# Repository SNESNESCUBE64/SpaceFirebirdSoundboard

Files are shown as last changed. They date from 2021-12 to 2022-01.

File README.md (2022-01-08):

# Space Firebird Soundboard Reproduction
This was my attempt at making a reproduction sound board for Space Firebird. It is a pretty fun game but I was having problems finding the sound boards. This reproduction board is not a 1:1 recreation, that would be silly. But it should fit in an original cocktail table or upright but that is not confirmed. I have a couple quality of life improvements, like for example all axial capacitors have been replaced with radials. I also used copper pours for the grounding in this. It does roughly follow the original layout however. These are not going to be really for sale by myself, which is why I am uploading the files so you can make your own!

**Status**: Prototype PCBs were assembled and tested as functional.

## Schematic Notes
Believe it or not, there were actually a couple of mistakes in the original schematics. The first one is IC12 pin 13. In the original schematics, it connects to pin 6 of IC9, this is incorrect, it should be connected to pin 4. Another thing I corrected is in later revisions of the sound board, they added two capacitors to the clear lines on the 74ls164s. Some older revisions have these capacitors hacked on, I went ahead and added them so hacks aren't necessary. One final thing I changed is if I read the schematics right, it was originally strapped for 2708 eproms, I changed the default to 2716 as those are much easier to program for.

## Images
**Front Render**   
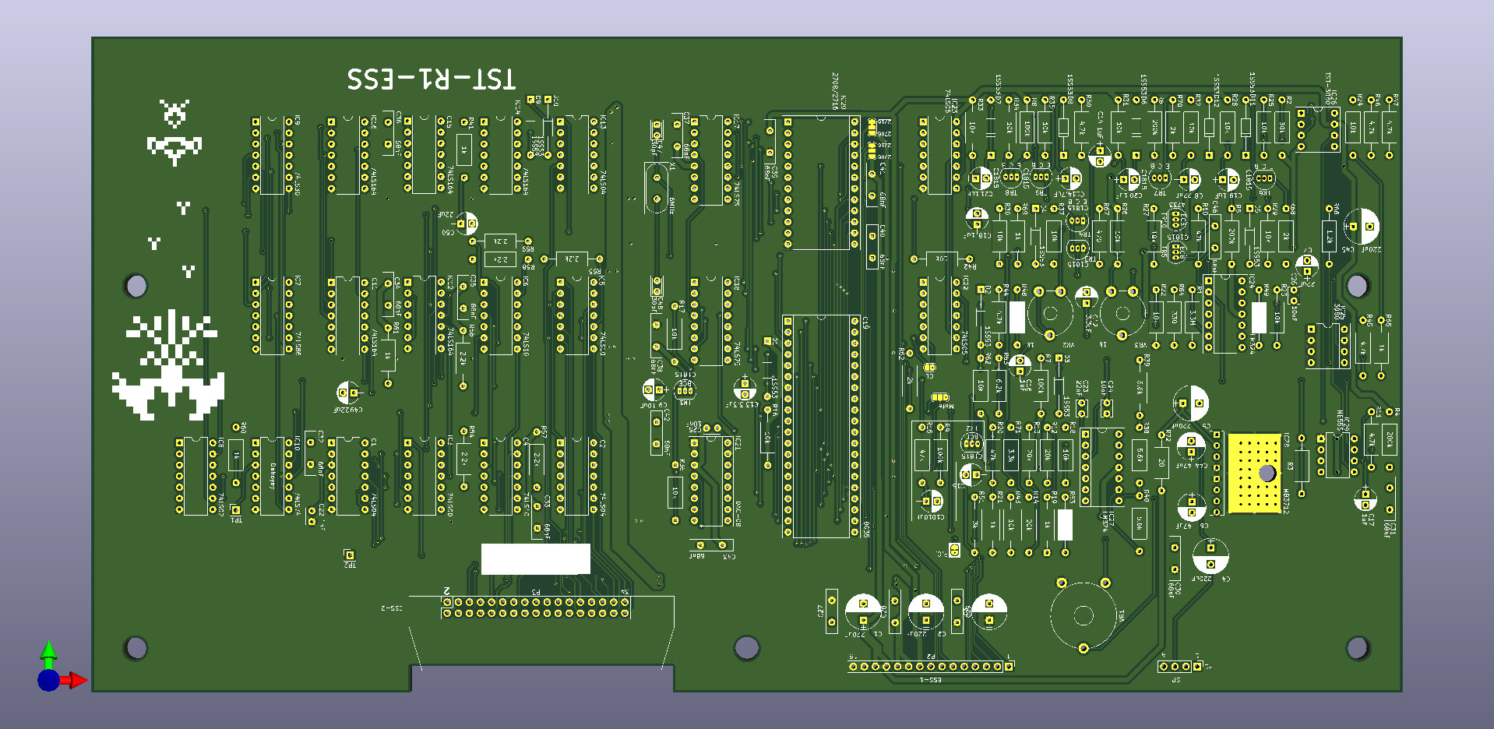
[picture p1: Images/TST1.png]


**Back Render**  
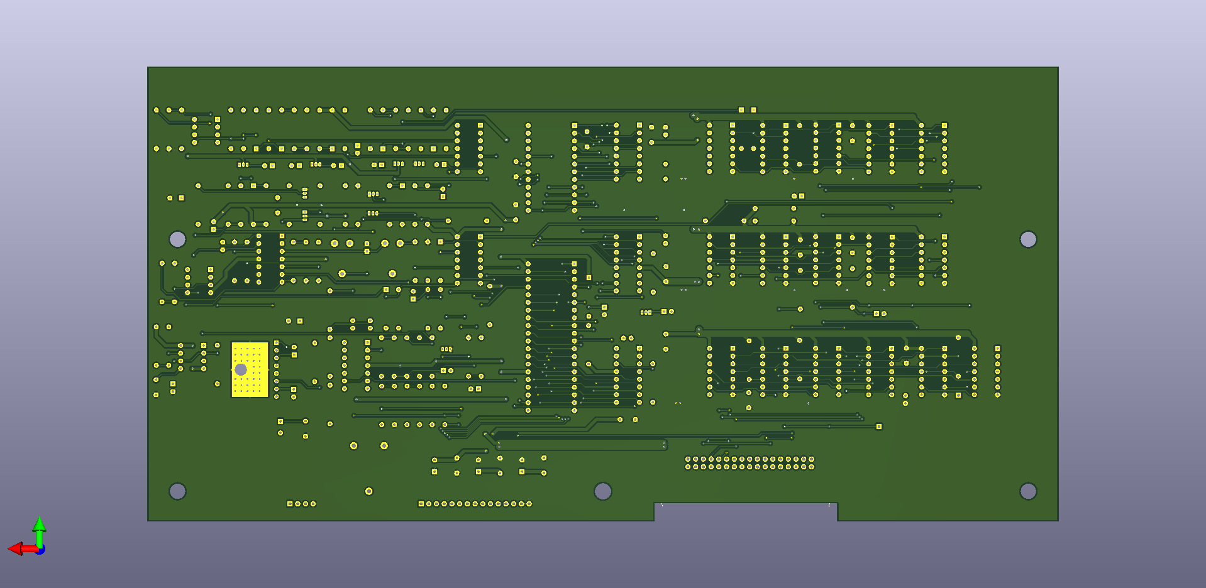
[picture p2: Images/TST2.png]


**Prototype PCB Front**  
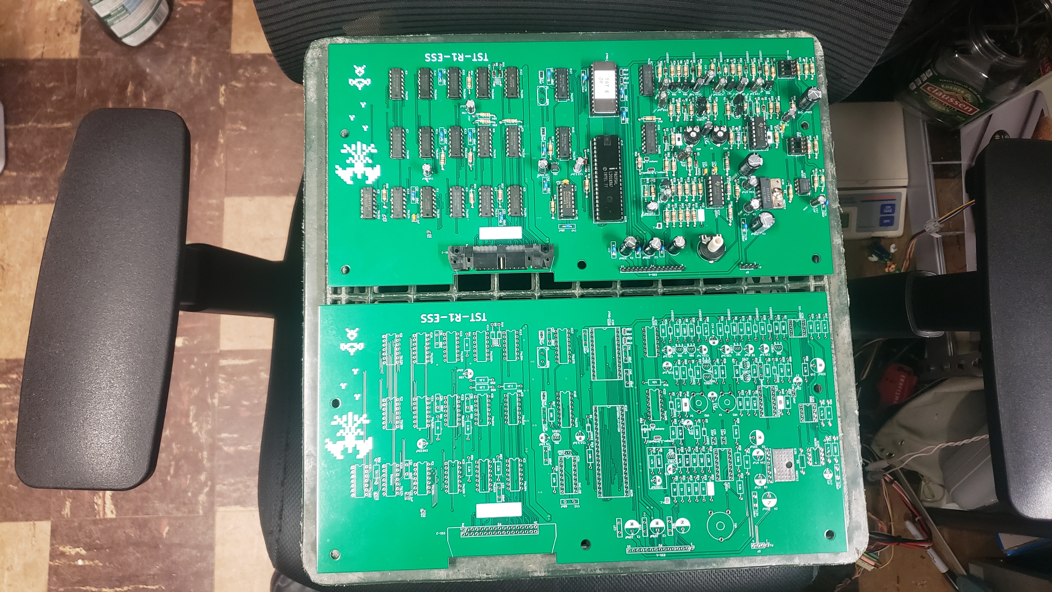
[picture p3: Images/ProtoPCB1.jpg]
Prototype Front


**Prototype PCB Back**  
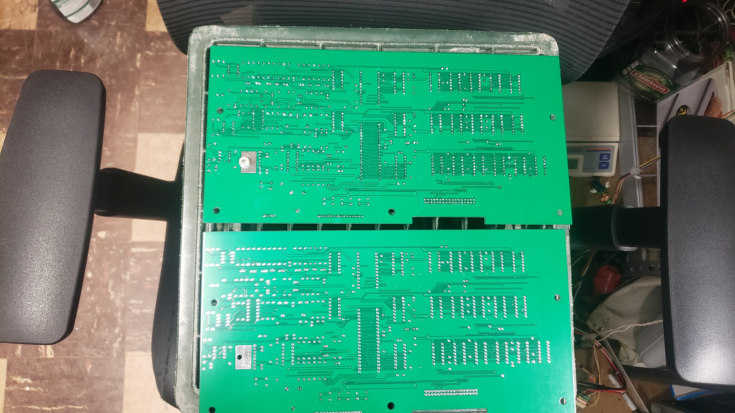
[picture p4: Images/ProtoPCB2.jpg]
Prototype Back


## Part Substitutions
- DAC-08
  - DAC0808LCN
- MB3712
  - ECG1423
  - NTE1423
- CA3080E (DIP Package Only)
  - LM3080N
  - ECG996
  - NTE996

## Bill of Materials
Most parts that are used on this sound board are off the shelf componts that are still made today. The only ones you might have a problem with are the eprom (strapped for 2716 by default), the 8035 CPU, CA3080E, and MB3712. Some components are not populated. X1, C47, C48, R48, R49, and R53 are not supposed to be populated. Some components are being substituted, for example: 1ss53 diodes are being substituted for 1N4148. 

|Item |Qty  |Reference(s) |Value |LibPart |Footprint |
|-----|---|---|---|---|---|
|1 |5 |C1, C2, C3, C4, C45 |220uF |Device:CP |Capacitors_THT:CP_Radial_D8.0mm_P3.80mm |
|2 |1 |C5 |220uf |Device:CP |Capacitors_THT:CP_Radial_D8.0mm_P3.80mm |
|3 |2 |C6, C44 |47uF |Device:CP |Capacitors_THT:CP_Radial_D6.3mm_P2.50mm |
|4 |4 |C7, C8, C49, C50 |22uF |Device:CP |Capacitors_THT:CP_Radial_D5.0mm_P2.50mm |
|5 |2 |C9, C10 |10uF |Device:CP |Capacitors_THT:CP_Radial_D5.0mm_P2.50mm |
|6 |1 |C11 |4.7uF |Device:CP |Capacitors_THT:CP_Radial_D5.0mm_P2.50mm |
|7 |2 |C12, C13 |3.3uF |Device:CP |Capacitors_THT:CP_Radial_D5.0mm_P2.50mm |
|8 |8 |C14, C15, C16, C17, C18, C19, C20, C21 |1uF |Device:CP |Capacitors_THT:CP_Radial_D5.0mm_P2.50mm |
|9 |1 |C22 |1nF |Device:C |Capacitors_THT:C_Disc_D3.8mm_W2.6mm_P2.50mm |
|10 |1 |C23 |22nF |Device:C |Capacitors_THT:C_Disc_D3.8mm_W2.6mm_P2.50mm |
|11 |3 |C24, C25, C26 |10nF |Device:C |Capacitors_THT:C_Disc_D3.8mm_W2.6mm_P2.50mm |
|12 |18 |C27, C28, C29, C30, C31, C32, C33, C34, C35, C36, C37, C38, C39, C40, C41, C42, C43, C46 |68nF |Device:C |Capacitors_THT:C_Disc_D10.0mm_W2.5mm_P5.00mm |
|13 |2 |C47, C48 |30pF |Device:C |Capacitors_THT:C_Disc_D3.4mm_W2.1mm_P2.50mm |
|14 |12 |D1, D2, D3, D4, D5, D6, D7, D8, D9, D10, D11, D12 |1SS53 (1N4148) |Device:D |Diodes_THT:D_DO-35_SOD27_P12.70mm_Horizontal |
|15 |3 |IC1, IC2, IC13 |74LS04 |74xx:74LS04 |Housings_DIP:DIP-14_W7.62mm |
|16 |1 |IC3 |74LS00 |74xx:74LS00 |Housings_DIP:DIP-14_W7.62mm |
|17 |3 |IC4, IC5, IC6 |74LS10 |74xx:74LS10 |Housings_DIP:DIP-14_W7.62mm |
|18 |1 |IC7 |74LS86 |74xx:74LS86 |Housings_DIP:DIP-14_W7.62mm |
|19 |1 |IC8 |74LS02 |74xx:74LS02 |Housings_DIP:DIP-14_W7.62mm |
|20 |1 |IC9 |74LS30 |74xx:74LS30 |Housings_DIP:DIP-14_W7.62mm |
|21 |1 |IC10 |74LS74 |74xx:74LS74 |Housings_DIP:DIP-14_W7.62mm |
|22 |5 |IC11, IC12, IC14, IC15, IC16 |74LS164 |Custom_Symbols:74LS164 |Housings_DIP:DIP-14_W7.62mm |
|23 |2 |IC17, IC18 |74LS75 |74xx:74LS75 |Housings_DIP:DIP-16_W7.62mm |
|24 |1 |IC19 |TST-8035 |Custom_Symbols:TST-8035 |Housings_DIP:DIP-40_W15.24mm_Socket |
|25 |1 |IC20 |TST-2708 |Custom_Symbols:TST-2716 |Housings_DIP:DIP-24_W15.24mm_Socket |
|26 |1 |IC21 |TST-DAC08 |Custom_Symbols:TST-DAC08 |Housings_DIP:DIP-16_W7.62mm_Socket |
|27 |2 |IC22, IC23 |74LS05 |74xx:74LS05 |Housings_DIP:DIP-14_W7.62mm |
|28 |2 |IC24, IC27 |LM324A |Amplifier_Operational:LM324A |Housings_DIP:DIP-14_W7.62mm_Socket |
|29 |2 |IC25, IC26 |TST-3080 |Custom_Symbols:TST-3080 |Housings_DIP:DIP-8_W7.62mm_Socket |
|30 |1 |IC28 |TST-MB3712 |Custom_Symbols:TST-MB3712 |Custom Footprints:MB3712 |
|31 |1 |IC29 |TST-NE555 |Custom_Symbols:TST-NE555 |Housings_DIP:DIP-8_W7.62mm |
|32 |3 |JP1, JP2, JP3 |Jumper_3_Bridged12 |Jumper:Jumper_3_Bridged12 |Jumpers:SolderJumper-3_P1.3mm_Bridged12_RoundedPad1.0x1.5mm_NumberLabels |
|33 |4 |JP4, JP5, JP6, JP7 |Jumper_2_Bridged |Jumper:Jumper_2_Bridged |Jumpers:SolderJumper-2_P1.3mm_Bridged_RoundedPad1.0x1.5mm |
|34 |1 |P1 |Conn_01x04 |Connector_Generic:Conn_01x04 |Pin_Headers:Pin_Header_Straight_1x04_Pitch2.54mm |
|35 |1 |P2 |Conn_01x15 |Connector_Generic:Conn_01x15 |Pin_Headers:Pin_Header_Straight_1x15_Pitch2.54mm |
|36 |1 |P3 |Conn_02x17_Odd_Even|Connector_Generic:Conn_02x17_Odd_Even|Custom Footprints:34_right_angle_ribbon |
|37 |1 |R1 |3.3M |Device:R |Custom Footprints:R_Axial_DIN0309_L7.0mm_D3.2mm_P12.70mm_Horizontal |
|38 |1 |R2 |30k |Device:R |Custom Footprints:R_Axial_DIN0309_L7.0mm_D3.2mm_P12.70mm_Horizontal |
|39 |1 |R3 |470k |Device:R |Custom Footprints:R_Axial_DIN0309_L7.0mm_D3.2mm_P12.70mm_Horizontal |
|40 |3 |R4, R5, R6 |200k |Device:R |Custom Footprints:R_Axial_DIN0309_L7.0mm_D3.2mm_P12.70mm_Horizontal |
|41 |3 |R7, R8, R9 |100k |Device:R |Custom Footprints:R_Axial_DIN0309_L7.0mm_D3.2mm_P12.70mm_Horizontal |
|42 |3 |R10, R15, R20 |47k |Device:R |Custom Footprints:R_Axial_DIN0309_L7.0mm_D3.2mm_P12.70mm_Horizontal |
|43 |6 |R11, R44, R45, R46, R47, R50 |4.7k |Device:R |Custom Footprints:R_Axial_DIN0309_L7.0mm_D3.2mm_P12.70mm_Horizontal |
|44 |3 |R12, R13, R14 |20k |Device:R |Custom Footprints:R_Axial_DIN0309_L7.0mm_D3.2mm_P12.70mm_Horizontal |
|45 |22 |R16, R17, R18, R22, R23, R24, R25, R26, R27, R28, R29, R30, R31, R32, R33, R34, R35, R36, R37, R42, R43, R62|10k |Device:R |Custom Footprints:R_Axial_DIN0309_L7.0mm_D3.2mm_P12.70mm_Horizontal |
|46 |7 |R19, R21, R41, R60, R61, R65, R69 |1k |Device:R |Custom Footprints:R_Axial_DIN0309_L7.0mm_D3.2mm_P12.70mm_Horizontal |
|47 |3 |R38, R39, R40 |5.6k |Device:R |Custom Footprints:R_Axial_DIN0309_L7.0mm_D3.2mm_P12.70mm_Horizontal |
|48 |2 |R48, R49 |1 |Device:R |Custom Footprints:R_Axial_DIN0309_L7.0mm_D3.2mm_P12.70mm_Horizontal |
|49 |1 |R51 |3k |Device:R |Custom Footprints:R_Axial_DIN0309_L7.0mm_D3.2mm_P12.70mm_Horizontal |
|50 |3 |R52, R68, R70 |2k |Device:R |Custom Footprints:R_Axial_DIN0309_L7.0mm_D3.2mm_P12.70mm_Horizontal |
|51 |1 |R53 |0 |Device:R |Custom Footprints:R_Axial_DIN0309_L7.0mm_D3.2mm_P12.70mm_Horizontal |
|52 |6 |R54, R55, R56, R57, R58, R59 |2.2k |Device:R |Custom Footprints:R_Axial_DIN0309_L7.0mm_D3.2mm_P12.70mm_Horizontal |
|53 |1 |R63 |6.2k |Device:R |Custom Footprints:R_Axial_DIN0309_L7.0mm_D3.2mm_P12.70mm_Horizontal |
|54 |1 |R64 |330 |Device:R |Custom Footprints:R_Axial_DIN0309_L7.0mm_D3.2mm_P12.70mm_Horizontal |
|55 |1 |R66 |1.2k |Device:R |Custom Footprints:R_Axial_DIN0309_L7.0mm_D3.2mm_P12.70mm_Horizontal |
|56 |1 |R67 |470 |Device:R |Custom Footprints:R_Axial_DIN0309_L7.0mm_D3.2mm_P12.70mm_Horizontal |
|57 |1 |R71 |3.3k |Device:R |Custom Footprints:R_Axial_DIN0309_L7.0mm_D3.2mm_P12.70mm_Horizontal |
|58 |1 |R72 |20 |Device:R |Custom Footprints:R_Axial_DIN0309_L7.0mm_D3.2mm_P12.70mm_Horizontal |
|59 |9 |TR1, TR2, TR3, TR4, TR5, TR6, TR7, TR8, TR9 |2SC1815 |Transistor_BJT:2SC1815 |TO_SOT_Packages_THT:TO-92_Inline_Narrow_Oval |
|60 |1 |TR10 |2SA733 |Device:Q_PNP_ECB |TO_SOT_Packages_THT:TO-92_Inline_Narrow_Oval |
|61 |1 |VR1 |10k |Device:R_POT |Potentiometers:Potentiometer_Trimmer_Piher_PT-15v15_Horizontal_Px15.0mm_Py10.0mm|
|62 |2 |VR2, VR3 |1k |Device:R_POT |Potentiometers:Potentiometer_Trimmer_Piher_PT-10v10_Horizontal_Px10.0mm_Py5.0mm |
|63 |1 |X1 |6MHz |Device:Crystal |Crystals:Crystal_HC18-U_Vertical |

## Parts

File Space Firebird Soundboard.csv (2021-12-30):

Source: | Space Firebird Soundboard.sch
Date: | 12/28/2021 20:36
Tool: | Eeschema (5.1.4)-1
Generator: | C:\Program Files\KiCad\bin\scripting\plugins/bom_csv_grouped_by_value.py
Component Count: | 187
Individual Components:
Item | Qty | Reference(s) | Value | LibPart | Footprint | Datasheet
 |  | C1 | 220uF | Device:CP | Capacitors_THT:CP_Radial_D8.0mm_P3.80mm | ~
 |  | C2 | 220uF | Device:CP | Capacitors_THT:CP_Radial_D8.0mm_P3.80mm | ~
 |  | C3 | 220uF | Device:CP | Capacitors_THT:CP_Radial_D8.0mm_P3.80mm | ~
 |  | C4 | 220uF | Device:CP | Capacitors_THT:CP_Radial_D8.0mm_P3.80mm | ~
 |  | C5 | 220uf | Device:CP | Capacitors_THT:CP_Radial_D8.0mm_P3.80mm | ~
 |  | C6 | 47uF | Device:CP | Capacitors_THT:CP_Radial_D6.3mm_P2.50mm | ~
 |  | C7 | 22uF | Device:CP | Capacitors_THT:CP_Radial_D5.0mm_P2.50mm | ~
 |  | C8 | 22uF | Device:CP | Capacitors_THT:CP_Radial_D5.0mm_P2.50mm | ~
 |  | C9 | 10uF | Device:CP | Capacitors_THT:CP_Radial_D5.0mm_P2.50mm | ~
 |  | C10 | 10uF | Device:CP | Capacitors_THT:CP_Radial_D5.0mm_P2.50mm | ~
 |  | C11 | 4.7uF | Device:CP | Capacitors_THT:CP_Radial_D5.0mm_P2.50mm | ~
 |  | C12 | 3.3uF | Device:CP | Capacitors_THT:CP_Radial_D5.0mm_P2.50mm | ~
 |  | C13 | 3.3uF | Device:CP | Capacitors_THT:CP_Radial_D5.0mm_P2.50mm | ~
 |  | C14 | 1uF | Device:CP | Capacitors_THT:CP_Radial_D5.0mm_P2.50mm | ~
 |  | C15 | 1uF | Device:CP | Capacitors_THT:CP_Radial_D5.0mm_P2.50mm | ~
 |  | C16 | 1uF | Device:CP | Capacitors_THT:CP_Radial_D5.0mm_P2.50mm | ~
 |  | C17 | 1uF | Device:CP | Capacitors_THT:CP_Radial_D5.0mm_P2.50mm | ~
 |  | C18 | 1uF | Device:CP | Capacitors_THT:CP_Radial_D5.0mm_P2.50mm | ~
 |  | C19 | 1uF | Device:CP | Capacitors_THT:CP_Radial_D5.0mm_P2.50mm | ~
 |  | C20 | 1uF | Device:CP | Capacitors_THT:CP_Radial_D5.0mm_P2.50mm | ~
 |  | C21 | 1uF | Device:CP | Capacitors_THT:CP_Radial_D5.0mm_P2.50mm | ~
 |  | C22 | 1nF | Device:C | Capacitors_THT:C_Disc_D3.8mm_W2.6mm_P2.50mm | ~
 |  | C23 | 22nF | Device:C | Capacitors_THT:C_Disc_D3.8mm_W2.6mm_P2.50mm | ~
 |  | C24 | 10nF | Device:C | Capacitors_THT:C_Disc_D3.8mm_W2.6mm_P2.50mm | ~
 |  | C25 | 10nF | Device:C | Capacitors_THT:C_Disc_D3.8mm_W2.6mm_P2.50mm | ~
 |  | C26 | 10nF | Device:C | Capacitors_THT:C_Disc_D3.8mm_W2.6mm_P2.50mm | ~
 |  | C27 | 68nF | Device:C | Capacitors_THT:C_Disc_D10.0mm_W2.5mm_P5.00mm | ~
 |  | C28 | 68nF | Device:C | Capacitors_THT:C_Disc_D10.0mm_W2.5mm_P5.00mm | ~
 |  | C29 | 68nF | Device:C | Capacitors_THT:C_Disc_D10.0mm_W2.5mm_P5.00mm | ~
 |  | C30 | 68nF | Device:C | Capacitors_THT:C_Disc_D10.0mm_W2.5mm_P5.00mm | ~
 |  | C31 | 68nF | Device:C | Capacitors_THT:C_Disc_D10.0mm_W2.5mm_P5.00mm | ~
 |  | C32 | 68nF | Device:C | Capacitors_THT:C_Disc_D10.0mm_W2.5mm_P5.00mm | ~
 |  | C33 | 68nF | Device:C | Capacitors_THT:C_Disc_D10.0mm_W2.5mm_P5.00mm | ~
 |  | C34 | 68nF | Device:C | Capacitors_THT:C_Disc_D10.0mm_W2.5mm_P5.00mm | ~
 |  | C35 | 68nF | Device:C | Capacitors_THT:C_Disc_D10.0mm_W2.5mm_P5.00mm | ~
 |  | C36 | 68nF | Device:C | Capacitors_THT:C_Disc_D10.0mm_W2.5mm_P5.00mm | ~
 |  | C37 | 68nF | Device:C | Capacitors_THT:C_Disc_D10.0mm_W2.5mm_P5.00mm | ~
 |  | C38 | 68nF | Device:C | Capacitors_THT:C_Disc_D10.0mm_W2.5mm_P5.00mm | ~
 |  | C39 | 68nF | Device:C | Capacitors_THT:C_Disc_D10.0mm_W2.5mm_P5.00mm | ~
 |  | C40 | 68nF | Device:C | Capacitors_THT:C_Disc_D10.0mm_W2.5mm_P5.00mm | ~
 |  | C41 | 68nF | Device:C | Capacitors_THT:C_Disc_D10.0mm_W2.5mm_P5.00mm | ~
 |  | C42 | 68nF | Device:C | Capacitors_THT:C_Disc_D10.0mm_W2.5mm_P5.00mm | ~
 |  | C43 | 68nF | Device:C | Capacitors_THT:C_Disc_D10.0mm_W2.5mm_P5.00mm | ~
 |  | C44 | 47uF | Device:CP | Capacitors_THT:CP_Radial_D6.3mm_P2.50mm | ~
 |  | C45 | 220uF | Device:CP | Capacitors_THT:CP_Radial_D8.0mm_P3.80mm | ~
 |  | C46 | 68nF | Device:C | Capacitors_THT:C_Disc_D10.0mm_W2.5mm_P5.00mm | ~
 |  | C47 | 30pF | Device:C | Capacitors_THT:C_Disc_D3.4mm_W2.1mm_P2.50mm | ~
 |  | C48 | 30pF | Device:C | Capacitors_THT:C_Disc_D3.4mm_W2.1mm_P2.50mm | ~
 |  | C49 | 22uF | Device:CP | Capacitors_THT:CP_Radial_D5.0mm_P2.50mm | ~
 |  | C50 | 22uF | Device:CP | Capacitors_THT:CP_Radial_D5.0mm_P2.50mm | ~
 |  | D1 | 1SS53 (1N4148) | Device:D | Diodes_THT:D_DO-35_SOD27_P12.70mm_Horizontal | ~
 |  | D2 | 1SS53 (1N4148) | Device:D | Diodes_THT:D_DO-35_SOD27_P12.70mm_Horizontal | ~
 |  | D3 | 1SS53 (1N4148) | Device:D | Diodes_THT:D_DO-35_SOD27_P12.70mm_Horizontal | ~
 |  | D4 | 1SS53 (1N4148) | Device:D | Diodes_THT:D_DO-35_SOD27_P12.70mm_Horizontal | ~
 |  | D5 | 1SS53 (1N4148) | Device:D | Diodes_THT:D_DO-35_SOD27_P12.70mm_Horizontal | ~
 |  | D6 | 1SS53 (1N4148) | Device:D | Diodes_THT:D_DO-35_SOD27_P12.70mm_Horizontal | ~
 |  | D7 | 1SS53 (1N4148) | Device:D | Diodes_THT:D_DO-35_SOD27_P12.70mm_Horizontal | ~
 |  | D8 | 1SS53 (1N4148) | Device:D | Diodes_THT:D_DO-35_SOD27_P12.70mm_Horizontal | ~
 |  | D9 | 1SS53 (1N4148) | Device:D | Diodes_THT:D_DO-35_SOD27_P12.70mm_Horizontal | ~
 |  | D10 | 1SS53 (1N4148) | Device:D | Diodes_THT:D_DO-35_SOD27_P12.70mm_Horizontal | ~
 |  | D11 | 1SS53 (1N4148) | Device:D | Diodes_THT:D_DO-35_SOD27_P12.70mm_Horizontal | ~
 |  | D12 | 1SS53 (1N4148) | Device:D | Diodes_THT:D_DO-35_SOD27_P12.70mm_Horizontal | ~
 |  | IC1 | 74LS04 | 74xx:74LS04 | Housings_DIP:DIP-14_W7.62mm | http://www.ti.com/lit/gpn/sn74LS04
 |  | IC2 | 74LS04 | 74xx:74LS04 | Housings_DIP:DIP-14_W7.62mm | http://www.ti.com/lit/gpn/sn74LS04
 |  | IC3 | 74LS00 | 74xx:74LS00 | Housings_DIP:DIP-14_W7.62mm | http://www.ti.com/lit/gpn/sn74ls00
 |  | IC4 | 74LS10 | 74xx:74LS10 | Housings_DIP:DIP-14_W7.62mm | http://www.ti.com/lit/gpn/sn74LS10
 |  | IC5 | 74LS10 | 74xx:74LS10 | Housings_DIP:DIP-14_W7.62mm | http://www.ti.com/lit/gpn/sn74LS10
 |  | IC6 | 74LS10 | 74xx:74LS10 | Housings_DIP:DIP-14_W7.62mm | http://www.ti.com/lit/gpn/sn74LS10
 |  | IC7 | 74LS86 | 74xx:74LS86 | Housings_DIP:DIP-14_W7.62mm | 74xx/74ls86.pdf
 |  | IC8 | 74LS02 | 74xx:74LS02 | Housings_DIP:DIP-14_W7.62mm | http://www.ti.com/lit/gpn/sn74ls02
 |  | IC9 | 74LS30 | 74xx:74LS30 | Housings_DIP:DIP-14_W7.62mm | http://www.ti.com/lit/gpn/sn74LS30
 |  | IC10 | 74LS74 | 74xx:74LS74 | Housings_DIP:DIP-14_W7.62mm | 74xx/74hc_hct74.pdf
 |  | IC11 | 74LS164 | Custom_Symbols:74LS164 | Housings_DIP:DIP-14_W7.62mm
 |  | IC12 | 74LS164 | Custom_Symbols:74LS164 | Housings_DIP:DIP-14_W7.62mm
 |  | IC13 | 74LS04 | 74xx:74LS04 | Housings_DIP:DIP-14_W7.62mm | http://www.ti.com/lit/gpn/sn74LS04
 |  | IC14 | 74LS164 | Custom_Symbols:74LS164 | Housings_DIP:DIP-14_W7.62mm
 |  | IC15 | 74LS164 | Custom_Symbols:74LS164 | Housings_DIP:DIP-14_W7.62mm
 |  | IC16 | 74LS164 | Custom_Symbols:74LS164 | Housings_DIP:DIP-14_W7.62mm
 |  | IC17 | 74LS75 | 74xx:74LS75 | Housings_DIP:DIP-16_W7.62mm | http://www.ti.com/lit/gpn/sn74LS75
 |  | IC18 | 74LS75 | 74xx:74LS75 | Housings_DIP:DIP-16_W7.62mm | http://www.ti.com/lit/gpn/sn74LS75
 |  | IC19 | TST-8035 | Custom_Symbols:TST-8035 | Housings_DIP:DIP-40_W15.24mm_Socket
 |  | IC20 | TST-2708 | Custom_Symbols:TST-2708 | Housings_DIP:DIP-24_W15.24mm_Socket
 |  | IC21 | TST-DAC08 | Custom_Symbols:TST-DAC08 | Housings_DIP:DIP-16_W7.62mm_Socket
 |  | IC22 | 74LS05 | 74xx:74LS05 | Housings_DIP:DIP-14_W7.62mm | http://www.ti.com/lit/gpn/sn74LS05
 |  | IC23 | 74LS05 | 74xx:74LS05 | Housings_DIP:DIP-14_W7.62mm | http://www.ti.com/lit/gpn/sn74LS05
 |  | IC24 | LM324A | Amplifier_Operational:LM324A | Housings_DIP:DIP-14_W7.62mm_Socket | http://www.ti.com/lit/ds/symlink/lm2902-n.pdf
 |  | IC25 | TST-3080 | Custom_Symbols:TST-3080 | Housings_DIP:DIP-8_W7.62mm_Socket
 |  | IC26 | TST-3080 | Custom_Symbols:TST-3080 | Housings_DIP:DIP-8_W7.62mm_Socket
 |  | IC27 | LM324A | Amplifier_Operational:LM324A | Housings_DIP:DIP-14_W7.62mm_Socket | http://www.ti.com/lit/ds/symlink/lm2902-n.pdf
 |  | IC28 | TST-MB3712 | Custom_Symbols:TST-MB3712 | Custom Footprints:MB3712
 |  | IC29 | TST-NE555 | Custom_Symbols:TST-NE555 | Housings_DIP:DIP-8_W7.62mm
 |  | JP1 | Jumper_3_Bridged12 | Jumper:Jumper_3_Bridged12 | Jumpers:SolderJumper-3_P1.3mm_Bridged12_RoundedPad1.0x1.5mm_NumberLabels | ~
 |  | JP2 | Jumper_3_Bridged12 | Jumper:Jumper_3_Bridged12 | Jumpers:SolderJumper-3_P1.3mm_Bridged12_RoundedPad1.0x1.5mm_NumberLabels | ~
 |  | JP3 | Jumper_3_Bridged12 | Jumper:Jumper_3_Bridged12 | Jumpers:SolderJumper-3_P1.3mm_Bridged12_RoundedPad1.0x1.5mm_NumberLabels | ~
 |  | JP4 | Jumper_2_Bridged | Jumper:Jumper_2_Bridged | Jumpers:SolderJumper-2_P1.3mm_Bridged_RoundedPad1.0x1.5mm | ~
 |  | JP5 | Jumper_2_Bridged | Jumper:Jumper_2_Bridged | Jumpers:SolderJumper-2_P1.3mm_Bridged_RoundedPad1.0x1.5mm | ~
 |  | JP6 | Jumper_2_Bridged | Jumper:Jumper_2_Bridged | Jumpers:SolderJumper-2_P1.3mm_Bridged_RoundedPad1.0x1.5mm | ~
 |  | JP7 | Jumper_2_Bridged | Jumper:Jumper_2_Bridged | Jumpers:SolderJumper-2_P1.3mm_Bridged_RoundedPad1.0x1.5mm | ~
 |  | P1 | Conn_01x04 | Connector_Generic:Conn_01x04 | Pin_Headers:Pin_Header_Straight_1x04_Pitch2.54mm | ~
 |  | P2 | Conn_01x15 | Connector_Generic:Conn_01x15 | Pin_Headers:Pin_Header_Straight_1x15_Pitch2.54mm | ~
 |  | P3 | Conn_02x17_Odd_Even | Connector_Generic:Conn_02x17_Odd_Even | Custom Footprints:34_right_angle_ribbon | ~
 |  | R1 | 3.3M | Device:R | Custom Footprints:R_Axial_DIN0309_L7.0mm_D3.2mm_P12.70mm_Horizontal | ~
 |  | R2 | 30k | Device:R | Custom Footprints:R_Axial_DIN0309_L7.0mm_D3.2mm_P12.70mm_Horizontal | ~
 |  | R3 | 470k | Device:R | Custom Footprints:R_Axial_DIN0309_L7.0mm_D3.2mm_P12.70mm_Horizontal | ~
 |  | R4 | 200k | Device:R | Custom Footprints:R_Axial_DIN0309_L7.0mm_D3.2mm_P12.70mm_Horizontal | ~
 |  | R5 | 200k | Device:R | Custom Footprints:R_Axial_DIN0309_L7.0mm_D3.2mm_P12.70mm_Horizontal | ~
 |  | R6 | 200k | Device:R | Custom Footprints:R_Axial_DIN0309_L7.0mm_D3.2mm_P12.70mm_Horizontal | ~
 |  | R7 | 100k | Device:R | Custom Footprints:R_Axial_DIN0309_L7.0mm_D3.2mm_P12.70mm_Horizontal | ~
 |  | R8 | 100k | Device:R | Custom Footprints:R_Axial_DIN0309_L7.0mm_D3.2mm_P12.70mm_Horizontal | ~
 |  | R9 | 100k | Device:R | Custom Footprints:R_Axial_DIN0309_L7.0mm_D3.2mm_P12.70mm_Horizontal | ~
 |  | R10 | 47k | Device:R | Custom Footprints:R_Axial_DIN0309_L7.0mm_D3.2mm_P12.70mm_Horizontal | ~
 |  | R11 | 4.7k | Device:R | Custom Footprints:R_Axial_DIN0309_L7.0mm_D3.2mm_P12.70mm_Horizontal | ~
 |  | R12 | 20k | Device:R | Custom Footprints:R_Axial_DIN0309_L7.0mm_D3.2mm_P12.70mm_Horizontal | ~
 |  | R13 | 20k | Device:R | Custom Footprints:R_Axial_DIN0309_L7.0mm_D3.2mm_P12.70mm_Horizontal | ~
 |  | R14 | 20k | Device:R | Custom Footprints:R_Axial_DIN0309_L7.0mm_D3.2mm_P12.70mm_Horizontal | ~
 |  | R15 | 47k | Device:R | Custom Footprints:R_Axial_DIN0309_L7.0mm_D3.2mm_P12.70mm_Horizontal | ~
 |  | R16 | 10k | Device:R | Custom Footprints:R_Axial_DIN0309_L7.0mm_D3.2mm_P12.70mm_Horizontal | ~
 |  | R17 | 10k | Device:R | Custom Footprints:R_Axial_DIN0309_L7.0mm_D3.2mm_P12.70mm_Horizontal | ~
 |  | R18 | 10k | Device:R | Custom Footprints:R_Axial_DIN0309_L7.0mm_D3.2mm_P12.70mm_Horizontal | ~
 |  | R19 | 1k | Device:R | Custom Footprints:R_Axial_DIN0309_L7.0mm_D3.2mm_P12.70mm_Horizontal | ~
 |  | R20 | 47k | Device:R | Custom Footprints:R_Axial_DIN0309_L7.0mm_D3.2mm_P12.70mm_Horizontal | ~
 |  | R21 | 1k | Device:R | Custom Footprints:R_Axial_DIN0309_L7.0mm_D3.2mm_P12.70mm_Horizontal | ~
 |  | R22 | 10k | Device:R | Custom Footprints:R_Axial_DIN0309_L7.0mm_D3.2mm_P12.70mm_Horizontal | ~
 |  | R23 | 10k | Device:R | Custom Footprints:R_Axial_DIN0309_L7.0mm_D3.2mm_P12.70mm_Horizontal | ~
 |  | R24 | 10k | Device:R | Custom Footprints:R_Axial_DIN0309_L7.0mm_D3.2mm_P12.70mm_Horizontal | ~
 |  | R25 | 10k | Device:R | Custom Footprints:R_Axial_DIN0309_L7.0mm_D3.2mm_P12.70mm_Horizontal | ~
 |  | R26 | 10k | Device:R | Custom Footprints:R_Axial_DIN0309_L7.0mm_D3.2mm_P12.70mm_Horizontal | ~
 |  | R27 | 10k | Device:R | Custom Footprints:R_Axial_DIN0309_L7.0mm_D3.2mm_P12.70mm_Horizontal | ~
 |  | R28 | 10k | Device:R | Custom Footprints:R_Axial_DIN0309_L7.0mm_D3.2mm_P12.70mm_Horizontal | ~
 |  | R29 | 10k | Device:R | Custom Footprints:R_Axial_DIN0309_L7.0mm_D3.2mm_P12.70mm_Horizontal | ~
 |  | R30 | 10k | Device:R | Custom Footprints:R_Axial_DIN0309_L7.0mm_D3.2mm_P12.70mm_Horizontal | ~
 |  | R31 | 10k | Device:R | Custom Footprints:R_Axial_DIN0309_L7.0mm_D3.2mm_P12.70mm_Horizontal | ~
 |  | R32 | 10k | Device:R | Custom Footprints:R_Axial_DIN0309_L7.0mm_D3.2mm_P12.70mm_Horizontal | ~
 |  | R33 | 10k | Device:R | Custom Footprints:R_Axial_DIN0309_L7.0mm_D3.2mm_P12.70mm_Horizontal | ~
 |  | R34 | 10k | Device:R | Custom Footprints:R_Axial_DIN0309_L7.0mm_D3.2mm_P12.70mm_Horizontal | ~
 |  | R35 | 10k | Device:R | Custom Footprints:R_Axial_DIN0309_L7.0mm_D3.2mm_P12.70mm_Horizontal | ~
 |  | R36 | 10k | Device:R | Custom Footprints:R_Axial_DIN0309_L7.0mm_D3.2mm_P12.70mm_Horizontal | ~
 |  | R37 | 10k | Device:R | Custom Footprints:R_Axial_DIN0309_L7.0mm_D3.2mm_P12.70mm_Horizontal | ~
 |  | R38 | 5.6k | Device:R | Custom Footprints:R_Axial_DIN0309_L7.0mm_D3.2mm_P12.70mm_Horizontal | ~
 |  | R39 | 5.6k | Device:R | Custom Footprints:R_Axial_DIN0309_L7.0mm_D3.2mm_P12.70mm_Horizontal | ~
 |  | R40 | 5.6k | Device:R | Custom Footprints:R_Axial_DIN0309_L7.0mm_D3.2mm_P12.70mm_Horizontal | ~
 |  | R41 | 1k | Device:R | Custom Footprints:R_Axial_DIN0309_L7.0mm_D3.2mm_P12.70mm_Horizontal | ~
 |  | R42 | 10k | Device:R | Custom Footprints:R_Axial_DIN0309_L7.0mm_D3.2mm_P12.70mm_Horizontal | ~
 |  | R43 | 10k | Device:R | Custom Footprints:R_Axial_DIN0309_L7.0mm_D3.2mm_P12.70mm_Horizontal | ~
 |  | R44 | 4.7k | Device:R | Custom Footprints:R_Axial_DIN0309_L7.0mm_D3.2mm_P12.70mm_Horizontal | ~
 |  | R45 | 4.7k | Device:R | Custom Footprints:R_Axial_DIN0309_L7.0mm_D3.2mm_P12.70mm_Horizontal | ~
 |  | R46 | 4.7k | Device:R | Custom Footprints:R_Axial_DIN0309_L7.0mm_D3.2mm_P12.70mm_Horizontal | ~
 |  | R47 | 4.7k | Device:R | Custom Footprints:R_Axial_DIN0309_L7.0mm_D3.2mm_P12.70mm_Horizontal | ~
 |  | R48 | 1 | Device:R | Custom Footprints:R_Axial_DIN0309_L7.0mm_D3.2mm_P12.70mm_Horizontal | ~
 |  | R49 | 1 | Device:R | Custom Footprints:R_Axial_DIN0309_L7.0mm_D3.2mm_P12.70mm_Horizontal | ~
 |  | R50 | 4.7k | Device:R | Custom Footprints:R_Axial_DIN0309_L7.0mm_D3.2mm_P12.70mm_Horizontal | ~
 |  | R51 | 3k | Device:R | Custom Footprints:R_Axial_DIN0309_L7.0mm_D3.2mm_P12.70mm_Horizontal | ~
 |  | R52 | 2k | Device:R | Custom Footprints:R_Axial_DIN0309_L7.0mm_D3.2mm_P12.70mm_Horizontal | ~
 |  | R53 | 0 | Device:R | Custom Footprints:R_Axial_DIN0309_L7.0mm_D3.2mm_P12.70mm_Horizontal | ~
 |  | R54 | 2.2k | Device:R | Custom Footprints:R_Axial_DIN0309_L7.0mm_D3.2mm_P12.70mm_Horizontal | ~
 |  | R55 | 2.2k | Device:R | Custom Footprints:R_Axial_DIN0309_L7.0mm_D3.2mm_P12.70mm_Horizontal | ~
 |  | R56 | 2.2k | Device:R | Custom Footprints:R_Axial_DIN0309_L7.0mm_D3.2mm_P12.70mm_Horizontal | ~
 |  | R57 | 2.2k | Device:R | Custom Footprints:R_Axial_DIN0309_L7.0mm_D3.2mm_P12.70mm_Horizontal | ~
 |  | R58 | 2.2k | Device:R | Custom Footprints:R_Axial_DIN0309_L7.0mm_D3.2mm_P12.70mm_Horizontal | ~
 |  | R59 | 2.2k | Device:R | Custom Footprints:R_Axial_DIN0309_L7.0mm_D3.2mm_P12.70mm_Horizontal | ~
 |  | R60 | 1k | Device:R | Custom Footprints:R_Axial_DIN0309_L7.0mm_D3.2mm_P12.70mm_Horizontal | ~
 |  | R61 | 1k | Device:R | Custom Footprints:R_Axial_DIN0309_L7.0mm_D3.2mm_P12.70mm_Horizontal | ~
 |  | R62 | 10k | Device:R | Custom Footprints:R_Axial_DIN0309_L7.0mm_D3.2mm_P12.70mm_Horizontal | ~
 |  | R63 | 6.2k | Device:R | Custom Footprints:R_Axial_DIN0309_L7.0mm_D3.2mm_P12.70mm_Horizontal | ~
 |  | R64 | 330 | Device:R | Custom Footprints:R_Axial_DIN0309_L7.0mm_D3.2mm_P12.70mm_Horizontal | ~
 |  | R65 | 1k | Device:R | Custom Footprints:R_Axial_DIN0309_L7.0mm_D3.2mm_P12.70mm_Horizontal | ~
 |  | R66 | 1.2k | Device:R | Custom Footprints:R_Axial_DIN0309_L7.0mm_D3.2mm_P12.70mm_Horizontal | ~
 |  | R67 | 470 | Device:R | Custom Footprints:R_Axial_DIN0309_L7.0mm_D3.2mm_P12.70mm_Horizontal | ~
 |  | R68 | 2k | Device:R | Custom Footprints:R_Axial_DIN0309_L7.0mm_D3.2mm_P12.70mm_Horizontal | ~
 |  | R69 | 1k | Device:R | Custom Footprints:R_Axial_DIN0309_L7.0mm_D3.2mm_P12.70mm_Horizontal | ~
 |  | R70 | 2k | Device:R | Custom Footprints:R_Axial_DIN0309_L7.0mm_D3.2mm_P12.70mm_Horizontal | ~
 |  | R71 | 3.3k | Device:R | Custom Footprints:R_Axial_DIN0309_L7.0mm_D3.2mm_P12.70mm_Horizontal | ~
 |  | R72 | 20 | Device:R | Custom Footprints:R_Axial_DIN0309_L7.0mm_D3.2mm_P12.70mm_Horizontal | ~
 |  | TR1 | 2SC1815 | Transistor_BJT:2SC1815 | TO_SOT_Packages_THT:TO-92_Inline_Narrow_Oval | https://media.digikey.com/pdf/Data%20Sheets/Toshiba%20PDFs/2SC1815.pdf
 |  | TR2 | 2SC1815 | Transistor_BJT:2SC1815 | TO_SOT_Packages_THT:TO-92_Inline_Narrow_Oval | https://media.digikey.com/pdf/Data%20Sheets/Toshiba%20PDFs/2SC1815.pdf
 |  | TR3 | 2SC1815 | Transistor_BJT:2SC1815 | TO_SOT_Packages_THT:TO-92_Inline_Narrow_Oval | https://media.digikey.com/pdf/Data%20Sheets/Toshiba%20PDFs/2SC1815.pdf
 |  | TR4 | 2SC1815 | Transistor_BJT:2SC1815 | TO_SOT_Packages_THT:TO-92_Inline_Narrow_Oval | https://media.digikey.com/pdf/Data%20Sheets/Toshiba%20PDFs/2SC1815.pdf
 |  | TR5 | 2SC1815 | Transistor_BJT:2SC1815 | TO_SOT_Packages_THT:TO-92_Inline_Narrow_Oval | https://media.digikey.com/pdf/Data%20Sheets/Toshiba%20PDFs/2SC1815.pdf
 |  | TR6 | 2SC1815 | Transistor_BJT:2SC1815 | TO_SOT_Packages_THT:TO-92_Inline_Narrow_Oval | https://media.digikey.com/pdf/Data%20Sheets/Toshiba%20PDFs/2SC1815.pdf
 |  | TR7 | 2SC1815 | Transistor_BJT:2SC1815 | TO_SOT_Packages_THT:TO-92_Inline_Narrow_Oval | https://media.digikey.com/pdf/Data%20Sheets/Toshiba%20PDFs/2SC1815.pdf
 |  | TR8 | 2SC1815 | Transistor_BJT:2SC1815 | TO_SOT_Packages_THT:TO-92_Inline_Narrow_Oval | https://media.digikey.com/pdf/Data%20Sheets/Toshiba%20PDFs/2SC1815.pdf
 |  | TR9 | 2SC1815 | Transistor_BJT:2SC1815 | TO_SOT_Packages_THT:TO-92_Inline_Narrow_Oval | https://media.digikey.com/pdf/Data%20Sheets/Toshiba%20PDFs/2SC1815.pdf
 |  | TR10 | 2SA733 | Device:Q_PNP_ECB | TO_SOT_Packages_THT:TO-92_Inline_Narrow_Oval | ~
 |  | VR1 | 10k | Device:R_POT | Potentiometers:Potentiometer_Trimmer_Piher_PT-15v15_Horizontal_Px15.0mm_Py10.0mm | ~
 |  | VR2 | 1k | Device:R_POT | Potentiometers:Potentiometer_Trimmer_Piher_PT-10v10_Horizontal_Px10.0mm_Py5.0mm | ~
 |  | VR3 | 1k | Device:R_POT | Potentiometers:Potentiometer_Trimmer_Piher_PT-10v10_Horizontal_Px10.0mm_Py5.0mm | ~
 |  | X1 | 6MHz | Device:Crystal | Crystals:Crystal_HC18-U_Vertical | ~
Collated Components:
Item | Qty | Reference(s) | Value | LibPart | Footprint | Datasheet
1 | 5 | C1, C2, C3, C4, C45 | 220uF | Device:CP | Capacitors_THT:CP_Radial_D8.0mm_P3.80mm | ~
2 | 1 | C5 | 220uf | Device:CP | Capacitors_THT:CP_Radial_D8.0mm_P3.80mm | ~
3 | 2 | C6, C44 | 47uF | Device:CP | Capacitors_THT:CP_Radial_D6.3mm_P2.50mm | ~
4 | 4 | C7, C8, C49, C50 | 22uF | Device:CP | Capacitors_THT:CP_Radial_D5.0mm_P2.50mm | ~
5 | 2 | C9, C10 | 10uF | Device:CP | Capacitors_THT:CP_Radial_D5.0mm_P2.50mm | ~
6 | 1 | C11 | 4.7uF | Device:CP | Capacitors_THT:CP_Radial_D5.0mm_P2.50mm | ~
7 | 2 | C12, C13 | 3.3uF | Device:CP | Capacitors_THT:CP_Radial_D5.0mm_P2.50mm | ~
8 | 8 | C14, C15, C16, C17, C18, C19, C20, C21 | 1uF | Device:CP | Capacitors_THT:CP_Radial_D5.0mm_P2.50mm | ~
9 | 1 | C22 | 1nF | Device:C | Capacitors_THT:C_Disc_D3.8mm_W2.6mm_P2.50mm | ~
10 | 1 | C23 | 22nF | Device:C | Capacitors_THT:C_Disc_D3.8mm_W2.6mm_P2.50mm | ~
11 | 3 | C24, C25, C26 | 10nF | Device:C | Capacitors_THT:C_Disc_D3.8mm_W2.6mm_P2.50mm | ~
12 | 18 | C27, C28, C29, C30, C31, C32, C33, C34, C35, C36, C37, C38, C39, C40, C41, C42, C43, C46 | 68nF | Device:C | Capacitors_THT:C_Disc_D10.0mm_W2.5mm_P5.00mm | ~
13 | 2 | C47, C48 | 30pF | Device:C | Capacitors_THT:C_Disc_D3.4mm_W2.1mm_P2.50mm | ~
14 | 12 | D1, D2, D3, D4, D5, D6, D7, D8, D9, D10, D11, D12 | 1SS53 (1N4148) | Device:D | Diodes_THT:D_DO-35_SOD27_P12.70mm_Horizontal | ~
15 | 3 | IC1, IC2, IC13 | 74LS04 | 74xx:74LS04 | Housings_DIP:DIP-14_W7.62mm | http://www.ti.com/lit/gpn/sn74LS04
16 | 1 | IC3 | 74LS00 | 74xx:74LS00 | Housings_DIP:DIP-14_W7.62mm | http://www.ti.com/lit/gpn/sn74ls00
17 | 3 | IC4, IC5, IC6 | 74LS10 | 74xx:74LS10 | Housings_DIP:DIP-14_W7.62mm | http://www.ti.com/lit/gpn/sn74LS10
18 | 1 | IC7 | 74LS86 | 74xx:74LS86 | Housings_DIP:DIP-14_W7.62mm | 74xx/74ls86.pdf
19 | 1 | IC8 | 74LS02 | 74xx:74LS02 | Housings_DIP:DIP-14_W7.62mm | http://www.ti.com/lit/gpn/sn74ls02
20 | 1 | IC9 | 74LS30 | 74xx:74LS30 | Housings_DIP:DIP-14_W7.62mm | http://www.ti.com/lit/gpn/sn74LS30
21 | 1 | IC10 | 74LS74 | 74xx:74LS74 | Housings_DIP:DIP-14_W7.62mm | 74xx/74hc_hct74.pdf
22 | 5 | IC11, IC12, IC14, IC15, IC16 | 74LS164 | Custom_Symbols:74LS164 | Housings_DIP:DIP-14_W7.62mm
23 | 2 | IC17, IC18 | 74LS75 | 74xx:74LS75 | Housings_DIP:DIP-16_W7.62mm | http://www.ti.com/lit/gpn/sn74LS75
24 | 1 | IC19 | TST-8035 | Custom_Symbols:TST-8035 | Housings_DIP:DIP-40_W15.24mm_Socket
25 | 1 | IC20 | TST-2708 | Custom_Symbols:TST-2708 | Housings_DIP:DIP-24_W15.24mm_Socket
26 | 1 | IC21 | TST-DAC08 | Custom_Symbols:TST-DAC08 | Housings_DIP:DIP-16_W7.62mm_Socket
27 | 2 | IC22, IC23 | 74LS05 | 74xx:74LS05 | Housings_DIP:DIP-14_W7.62mm | http://www.ti.com/lit/gpn/sn74LS05
28 | 2 | IC24, IC27 | LM324A | Amplifier_Operational:LM324A | Housings_DIP:DIP-14_W7.62mm_Socket | http://www.ti.com/lit/ds/symlink/lm2902-n.pdf
29 | 2 | IC25, IC26 | TST-3080 | Custom_Symbols:TST-3080 | Housings_DIP:DIP-8_W7.62mm_Socket
30 | 1 | IC28 | TST-MB3712 | Custom_Symbols:TST-MB3712 | Custom Footprints:MB3712
31 | 1 | IC29 | TST-NE555 | Custom_Symbols:TST-NE555 | Housings_DIP:DIP-8_W7.62mm
32 | 3 | JP1, JP2, JP3 | Jumper_3_Bridged12 | Jumper:Jumper_3_Bridged12 | Jumpers:SolderJumper-3_P1.3mm_Bridged12_RoundedPad1.0x1.5mm_NumberLabels | ~
33 | 4 | JP4, JP5, JP6, JP7 | Jumper_2_Bridged | Jumper:Jumper_2_Bridged | Jumpers:SolderJumper-2_P1.3mm_Bridged_RoundedPad1.0x1.5mm | ~
34 | 1 | P1 | Conn_01x04 | Connector_Generic:Conn_01x04 | Pin_Headers:Pin_Header_Straight_1x04_Pitch2.54mm | ~
35 | 1 | P2 | Conn_01x15 | Connector_Generic:Conn_01x15 | Pin_Headers:Pin_Header_Straight_1x15_Pitch2.54mm | ~
36 | 1 | P3 | Conn_02x17_Odd_Even | Connector_Generic:Conn_02x17_Odd_Even | Custom Footprints:34_right_angle_ribbon | ~
37 | 1 | R1 | 3.3M | Device:R | Custom Footprints:R_Axial_DIN0309_L7.0mm_D3.2mm_P12.70mm_Horizontal | ~
38 | 1 | R2 | 30k | Device:R | Custom Footprints:R_Axial_DIN0309_L7.0mm_D3.2mm_P12.70mm_Horizontal | ~
39 | 1 | R3 | 470k | Device:R | Custom Footprints:R_Axial_DIN0309_L7.0mm_D3.2mm_P12.70mm_Horizontal | ~
40 | 3 | R4, R5, R6 | 200k | Device:R | Custom Footprints:R_Axial_DIN0309_L7.0mm_D3.2mm_P12.70mm_Horizontal | ~
41 | 3 | R7, R8, R9 | 100k | Device:R | Custom Footprints:R_Axial_DIN0309_L7.0mm_D3.2mm_P12.70mm_Horizontal | ~
42 | 3 | R10, R15, R20 | 47k | Device:R | Custom Footprints:R_Axial_DIN0309_L7.0mm_D3.2mm_P12.70mm_Horizontal | ~
43 | 6 | R11, R44, R45, R46, R47, R50 | 4.7k | Device:R | Custom Footprints:R_Axial_DIN0309_L7.0mm_D3.2mm_P12.70mm_Horizontal | ~
44 | 3 | R12, R13, R14 | 20k | Device:R | Custom Footprints:R_Axial_DIN0309_L7.0mm_D3.2mm_P12.70mm_Horizontal | ~
45 | 22 | R16, R17, R18, R22, R23, R24, R25, R26, R27, R28, R29, R30, R31, R32, R33, R34, R35, R36, R37, R42, R43, R62 | 10k | Device:R | Custom Footprints:R_Axial_DIN0309_L7.0mm_D3.2mm_P12.70mm_Horizontal | ~
46 | 7 | R19, R21, R41, R60, R61, R65, R69 | 1k | Device:R | Custom Footprints:R_Axial_DIN0309_L7.0mm_D3.2mm_P12.70mm_Horizontal | ~
47 | 3 | R38, R39, R40 | 5.6k | Device:R | Custom Footprints:R_Axial_DIN0309_L7.0mm_D3.2mm_P12.70mm_Horizontal | ~
48 | 2 | R48, R49 | 1 | Device:R | Custom Footprints:R_Axial_DIN0309_L7.0mm_D3.2mm_P12.70mm_Horizontal | ~
49 | 1 | R51 | 3k | Device:R | Custom Footprints:R_Axial_DIN0309_L7.0mm_D3.2mm_P12.70mm_Horizontal | ~
50 | 3 | R52, R68, R70 | 2k | Device:R | Custom Footprints:R_Axial_DIN0309_L7.0mm_D3.2mm_P12.70mm_Horizontal | ~
51 | 1 | R53 | 0 | Device:R | Custom Footprints:R_Axial_DIN0309_L7.0mm_D3.2mm_P12.70mm_Horizontal | ~
52 | 6 | R54, R55, R56, R57, R58, R59 | 2.2k | Device:R | Custom Footprints:R_Axial_DIN0309_L7.0mm_D3.2mm_P12.70mm_Horizontal | ~
53 | 1 | R63 | 6.2k | Device:R | Custom Footprints:R_Axial_DIN0309_L7.0mm_D3.2mm_P12.70mm_Horizontal | ~
54 | 1 | R64 | 330 | Device:R | Custom Footprints:R_Axial_DIN0309_L7.0mm_D3.2mm_P12.70mm_Horizontal | ~
55 | 1 | R66 | 1.2k | Device:R | Custom Footprints:R_Axial_DIN0309_L7.0mm_D3.2mm_P12.70mm_Horizontal | ~
56 | 1 | R67 | 470 | Device:R | Custom Footprints:R_Axial_DIN0309_L7.0mm_D3.2mm_P12.70mm_Horizontal | ~
57 | 1 | R71 | 3.3k | Device:R | Custom Footprints:R_Axial_DIN0309_L7.0mm_D3.2mm_P12.70mm_Horizontal | ~
58 | 1 | R72 | 20 | Device:R | Custom Footprints:R_Axial_DIN0309_L7.0mm_D3.2mm_P12.70mm_Horizontal | ~
59 | 9 | TR1, TR2, TR3, TR4, TR5, TR6, TR7, TR8, TR9 | 2SC1815 | Transistor_BJT:2SC1815 | TO_SOT_Packages_THT:TO-92_Inline_Narrow_Oval | https://media.digikey.com/pdf/Data%20Sheets/Toshiba%20PDFs/2SC1815.pdf
60 | 1 | TR10 | 2SA733 | Device:Q_PNP_ECB | TO_SOT_Packages_THT:TO-92_Inline_Narrow_Oval | ~
61 | 1 | VR1 | 10k | Device:R_POT | Potentiometers:Potentiometer_Trimmer_Piher_PT-15v15_Horizontal_Px15.0mm_Py10.0mm | ~
62 | 2 | VR2, VR3 | 1k | Device:R_POT | Potentiometers:Potentiometer_Trimmer_Piher_PT-10v10_Horizontal_Px10.0mm_Py5.0mm | ~
63 | 1 | X1 | 6MHz | Device:Crystal | Crystals:Crystal_HC18-U_Vertical | ~

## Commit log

2021-12-27 Added the in-progress work
    [Space Firebird Soundboard.sch]
2021-12-30 Finished the first version of the board
    [Space Firebird Soundboard-B_Cu.gbr, Space Firebird Soundboard-B_Mask.gbr, Space Firebird Soundboard-B_Paste.gbr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]
2021-12-30 Fixed the BOM in the readme
2022-01-06 minor silk screen fixes
    [Space Firebird Soundboard-B_Cu.gbr, Space Firebird Soundboard-B_Mask.gbr, Space Firebird Soundboard-B_Paste.gbr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]
2022-01-06 Added pcb images
